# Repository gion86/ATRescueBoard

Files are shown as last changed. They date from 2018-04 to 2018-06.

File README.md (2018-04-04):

# ATRescueBoard
### Full credit for the original version to Jeff Keyzer [http://mightyohm.com](http://mightyohm.com)

Atmel "rescue" board for ATMega and ATTiny X4/X5: to recover fuses setting with High Voltage Programming. 

The PCB is a simplified Arduino shield, with sockets for ATMega and ATTiny; as 12V source the Vin Arduino 
pin has to be used, so the **Arduino must be powered externally with a 12V power supply!**

The micro code is uploaded to the ATmega328P on the Arduino, and comunicate with the user via the serial
interface. Three different mode can be selected:
* ATMEGA: mode for ATmega 128/168/328;
* TINY2313: not supported in this hardware version, look for original version at [https://mightyohm.com/blog/products/hv-rescue-shield-2-x/](https://mightyohm.com/blog/products/hv-rescue-shield-2-x/);
* HVSP: mode for ATtiny X4/X5;

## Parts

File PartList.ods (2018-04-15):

Part | Value | Device | Package | Library
ANA_IN |  | PINHD-1X6 | 1X06 | PIN HEADER | x
C1 | 100n | C-EU050-024X044 | C050-024X044 | CAPACITOR, European | x
DIG0_7 |  | PINHD-1X8 | 1X08 | PIN HEADER | x
DIG8_13 |  | PINHD-1X8 | 1X08 | PIN HEADER | x
LED1 | RED | LED5MM | LED5MM | MightyOhm Engineerin | x
LED2 | GREEN | LED5MM | LED5MM | MightyOhm Engineerin | x
MCU1 | ATMEGA | MEGA48/88/168-PU | DIL28-3 |  | x
MCU2 | ATTINY84ATTINY84-20PU | ATTINY84ATTINY84-20PU | DIL14 | Atmel 14-pin 2/4/8kB | x
MCU3 | TINY85-20-DIP | ATTINY45TINY85-20-DIP | DIP08 | Atmel 8-pin 2/4/8kB | x
POWER |  | PINHD-1X7 | 1X07 | PIN HEADER | x
Q1 | 2N3904 | 2N3904 | TO92- | NPN Transistor | x
R1 | 1k | R-US_0204/7 | 0204/7 | RESISTOR, American s | x
R2 | 5K6 | R-US_0207/10 | 0207/10 | RESISTOR, American s | x
R3 | 390 | R-US_0309/12 | 0309/12 | RESISTOR, American s | x
R4 | 560 | R-US_0309/12 | 0309/12 | RESISTOR, American s | x
R5 | 4K7 | R-US_0204/7 | 0204/7 | RESISTOR, American s | x
R6 | 560 | R-US_0309/12 | 0309/12 | RESISTOR, American s | x
SW1 |  | SWITCH_PUSHBUTTONEVQ-PE | TACT_PANA-EVQ | Buttons | x
TP1 | 12V_SW | TPPTH | TP_PTH | Test Point | x

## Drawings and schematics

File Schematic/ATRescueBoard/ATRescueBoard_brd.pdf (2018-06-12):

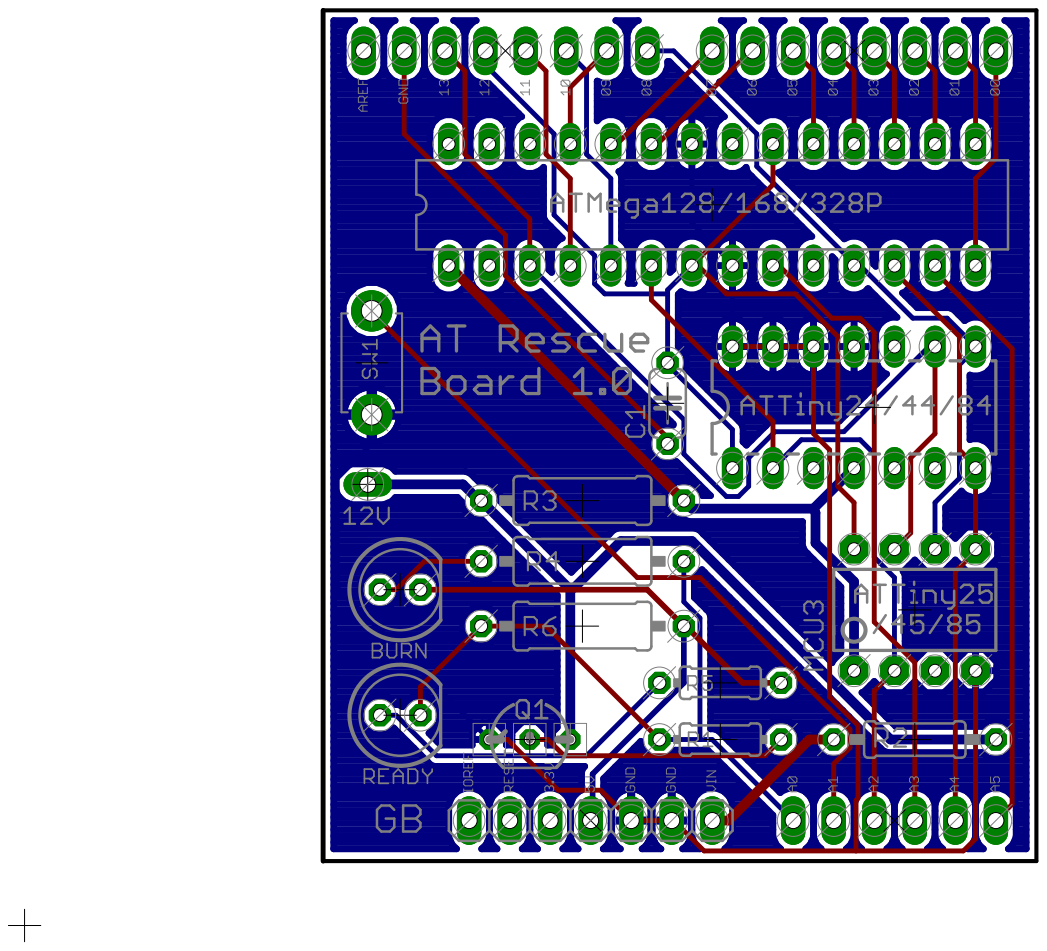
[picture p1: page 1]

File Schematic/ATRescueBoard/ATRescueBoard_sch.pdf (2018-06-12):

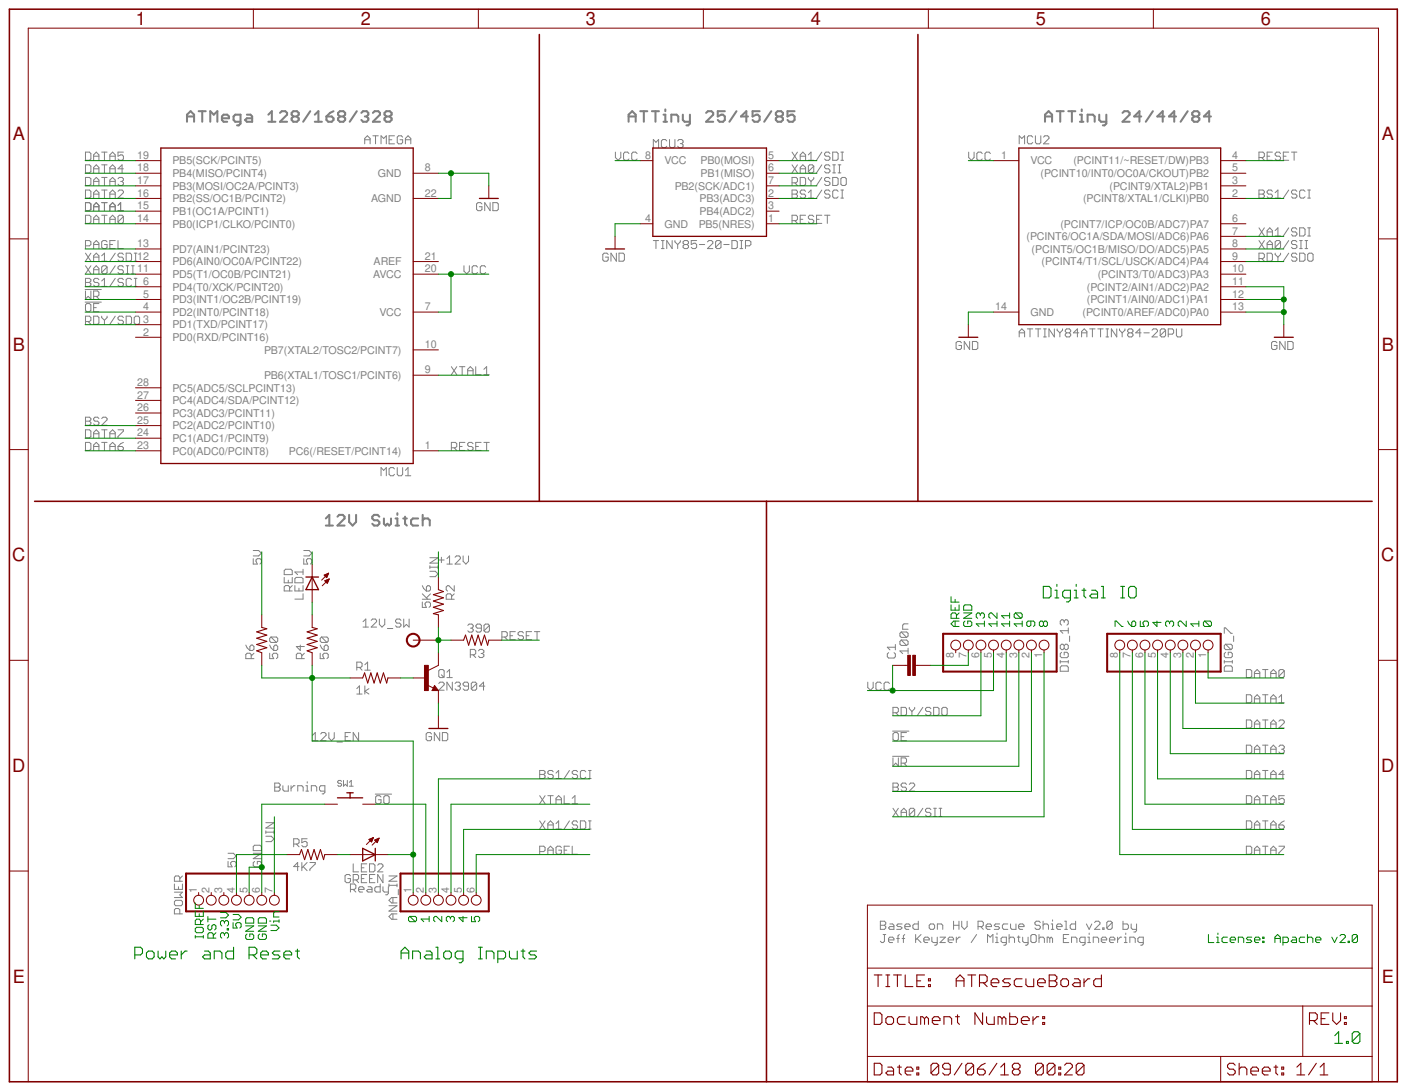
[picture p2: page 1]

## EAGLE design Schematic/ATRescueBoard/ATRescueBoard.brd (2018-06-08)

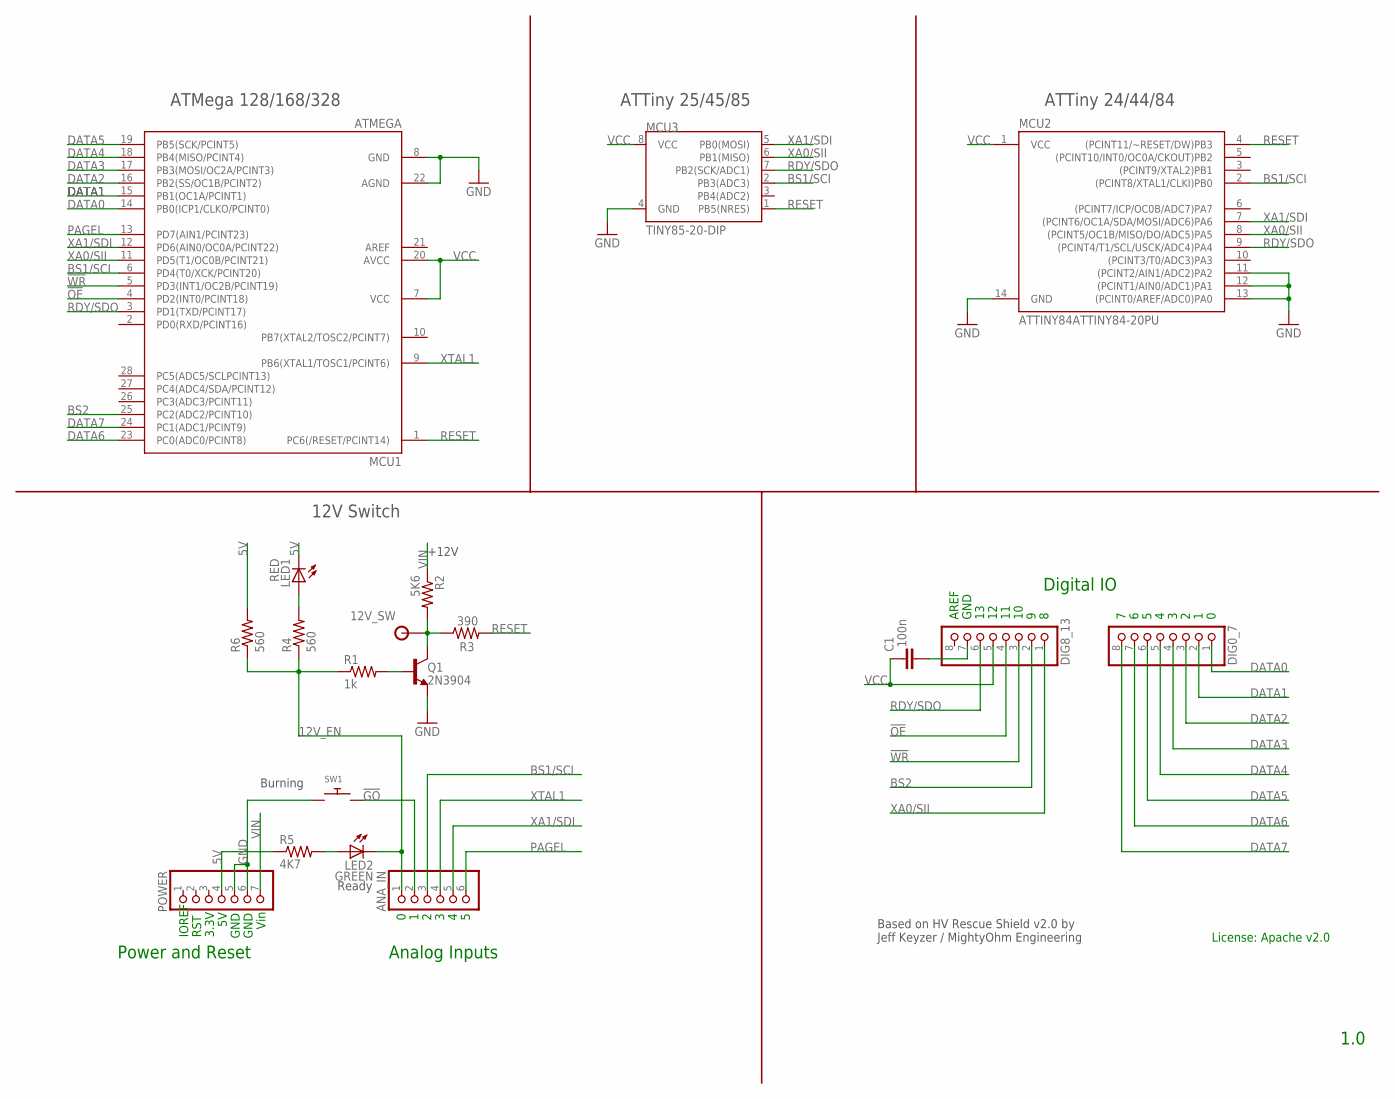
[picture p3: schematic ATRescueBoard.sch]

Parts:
ANA_IN: PINHD-1X6; 1X06
C1: 100n; C050-024X044
DIG0_7, DIG8_13: PINHD-1X8; 1X08
LED1: RED; LED5MM
LED2: GREEN; LED5MM
MCU1: ATMEGA; DIL28-3
MCU2: ATTINY84ATTINY84-20PU; DIL14
MCU3: TINY85-20-DIP; DIP08
POWER: PINHD-1X7; 1X07
Q1: 2N3904; TO92-
R1: 1k; 0204/7
R2: 5K6; 0207/10
R3: 390; 0309/12
R4, R6: 560; 0309/12
R5: 4K7; 0204/7
SW1: SWITCH_PUSHBUTTONEVQ-PE; TACT_PANA-EVQ
TP1: 12V_SW; TP_PTH

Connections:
5V: LED1.K (C), POWER.4, R5.1, R6.2
12V_EN: ANA_IN.1, LED2.K (C), R1.1, R4.1, R6.1
12V_SW: Q1.1 (C), R2.2, R3.1, TP1.P$1
!GO: ANA_IN.2, SW1.P$2
!OE: DIG8_13.4, MCU1.4 (PD2(INT0/PCINT18))
!WR: DIG8_13.3, MCU1.5 (PD3(INT1/OC2B/PCINT19))
BS1/SCI: ANA_IN.3, MCU1.6 (PD4(T0/XCK/PCINT20)), MCU2.2 ((PCINT8/XTAL1/CLKI)PB0), MCU3.2 (PB3(ADC3))
BS2: DIG8_13.2, MCU1.25 (PC2(ADC2/PCINT10))
DATA0: DIG0_7.1, MCU1.14 (PB0(ICP1/CLKO/PCINT0))
DATA1: DIG0_7.2, MCU1.15 (PB1(OC1A/PCINT1))
DATA2: DIG0_7.3, MCU1.16 (PB2(SS/OC1B/PCINT2))
DATA3: DIG0_7.4, MCU1.17 (PB3(MOSI/OC2A/PCINT3))
DATA4: DIG0_7.5, MCU1.18 (PB4(MISO/PCINT4))
DATA5: DIG0_7.6, MCU1.19 (PB5(SCK/PCINT5))
DATA6: DIG0_7.7, MCU1.23 (PC0(ADC0/PCINT8))
DATA7: DIG0_7.8, MCU1.24 (PC1(ADC1/PCINT9))
GND: MCU1.8 (GND), MCU1.22 (AGND), MCU2.11 ((PCINT2/AIN1/ADC2)PA2), MCU2.12 ((PCINT1/AIN0/ADC1)PA1), MCU2.13 ((PCINT0/AREF/ADC0)PA0), MCU2.14 (GND), MCU3.4 (GND), POWER.5, POWER.6, Q1.3 (E), SW1.P$1
unnamed: Q1.2 (B), R1.2
unnamed: LED1.A, R4.2
unnamed: LED2.A, R5.2
unnamed: C1.1, DIG8_13.7
PAGEL: ANA_IN.6, MCU1.13 (PD7(AIN1/PCINT23))
RDY/SDO: DIG8_13.6, MCU1.3 (PD1(TXD/PCINT17)), MCU2.9 ((PCINT4/T1/SCL/USCK/ADC4)PA4), MCU3.7 (PB2(SCK/ADC1))
RESET: MCU1.1 (PC6(/RESET/PCINT14)), MCU2.4 ((PCINT11/~RESET/DW)PB3), MCU3.1 (PB5(NRES)), R3.2
VCC: C1.2, DIG8_13.5, MCU1.7 (VCC), MCU1.20 (AVCC), MCU2.1 (VCC), MCU3.8 (VCC)
VIN: POWER.7, R2.1
XA0/SII: DIG8_13.1, MCU1.11 (PD5(T1/OC0B/PCINT21)), MCU2.8 ((PCINT5/OC1B/MISO/DO/ADC5)PA5), MCU3.6 (PB1(MISO))
XA1/SDI: ANA_IN.5, MCU1.12 (PD6(AIN0/OC0A/PCINT22)), MCU2.7 ((PCINT6/OC1A/SDA/MOSI/ADC6)PA6), MCU3.5 (PB0(MOSI))
XTAL1: ANA_IN.4, MCU1.9 (PB6(XTAL1/TOSC1/PCINT6))

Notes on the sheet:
Analog Inputs
Power and Reset
Digital IO
Vin
GND
RST
3.3V
Based on HV Rescue Shield v2.0 by Jeff Keyzer / MightyOhm Engineering
AREF
Ready
Burning
License: Apache v2.0
IOREF
+12V
ATTiny 25/45/85
ATMega 128/168/328
ATTiny 24/44/84
12V Switch

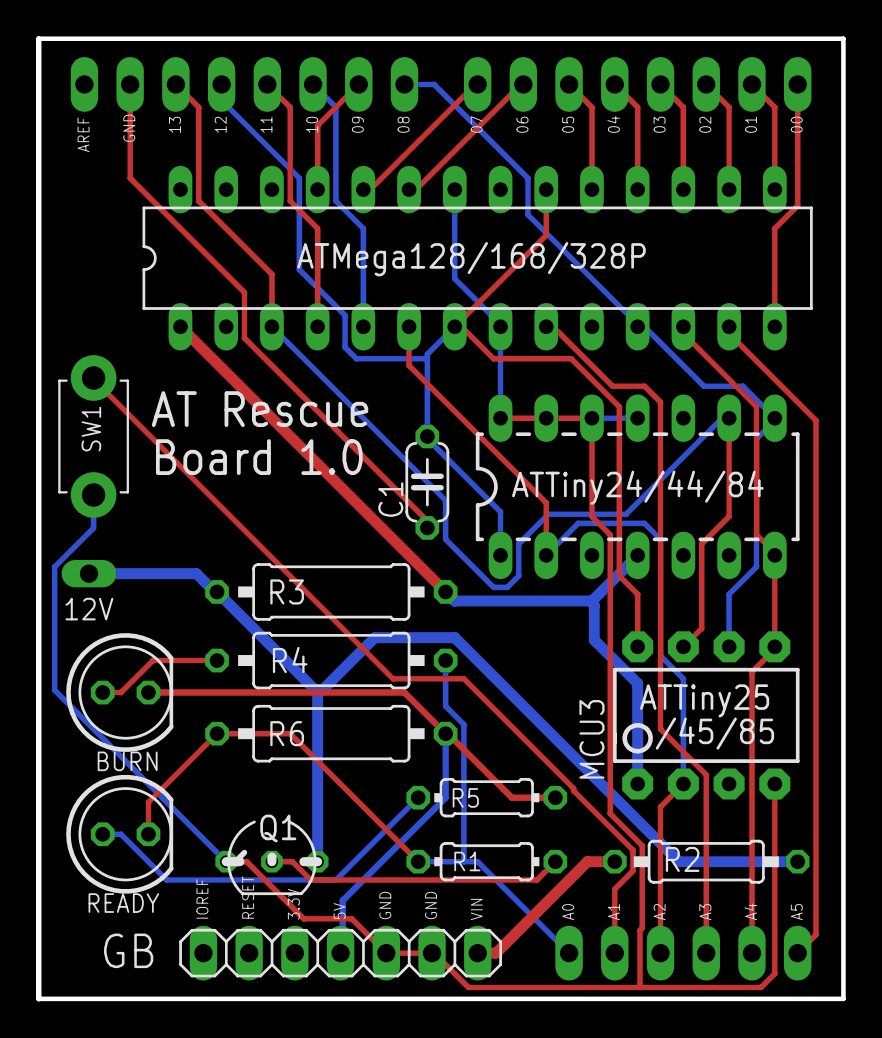
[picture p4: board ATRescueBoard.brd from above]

Board: 2 copper layers, 44.7 x 53.3 mm, 20 parts (0 on the bottom side), 29 nets.

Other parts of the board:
DRILEGEND: DRILEGEND

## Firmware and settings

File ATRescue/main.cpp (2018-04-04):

/*
  Title:        HVRescue_Shield
  Description:  Arduino sketch for use with the HV Rescue Shield
  Author:       Jeff Keyzer
  Company:      MightyOhm Engineering
  Website:      http://mightyohm.com
  Contact:      http://mightyohm.com/blog/contact/

  This sketch assumes that the Arduino is equipped with an AVR HV Rescue Shield.
  Schematics and other details are available at http://mightyohm.com/hvrescue2

  The sketch uses High Voltage Programming Mode to set fuses on many Atmel AVR family 8-bit microcontrollers.
  Version 2.0 adds support for High Voltage Serial Programming (HVSP) mode and 8-pin ATtiny devices, but remains
  backwards compatible with the 1.x series hardware.

  The HVPP routines are based on those described in the ATmega48/88/168 datasheet rev.
  2545M-AVR-09/07, pg. 290-297 and the ATtiny2313 datasheet rev. 2543I-AVR-04/06 pg. 165-176.

  The HVSP routines are based on the ATtiny25/45/85 and 13A datasheets (ATtiny25/45/85 2586M–AVR–07/10 pg. 159-165,
  ATtiny13A 8126E-AVR-7/10 pg. 109-116).

  These routines are compatible with many other members of the AVR family that are not listed here.
  For a complete list of tested microcontrollers, see http://mightyohm.com/wiki/products:hvrescue:compatibility

  Changelog:
  31/03/18 2.13 Gionata Boccalini
   - moved function on top of setup and loop (to compile without function prototypes)
   - changed the logic on RST pin: now is inverting
   - fixed some compiler warnings

  3/15/11 2.12
    - new digital pin 0-7 (command&data) read/write routines for the Arduino Mega, since these lines are implemented
      differently on the Mega than on the original Arduino.

  3/8/11 2.11
    - analog inputs (used here as digital outputs) are now called by their new Arduino A0-A5 names.

  2/2/11 2.1
    - adjusted RESET and VCC edge timing to work with new board design and avoid signal contention on SDO
    - fixed bug that prevented program from compiling in non-interactive mode
    - modified non-interactive mode so that read/verify serial comms still occur, but fuse values aren't prompted

  12/17/10 2.01
    - added missing braces to if(mode == HVSP) that sets SDO pinmode to INPUT
    - removed misleading comment about removing AVR when entering fuse values
    - default mode changed back to ATMEGA

  12/13/10 v2.0
    - Added support for 8-pin parts that use HV Serial Programming (HVSP)
    - New mode selection at startup determines which type of part is to be programmed
    - Got rid of endSerial function, since Arduino now includes Serial.end (finally!)
    - Added a wait for serial transmit to complete before burning fuses.  Without this HFUSE burn would fail occasionally.
    - Numerous other minor tweaks, removal of unnecessary delays, better commenting

  9/24/10 v1.2a
    - ATtiny2313 mode was being set by default.  Changed default mode back to ATmega (see #define ATtiny).

  8/16/10 v1.2
    - Existing fuse settings are now shown before asking the user for new values
    - Added OE strobe after entering programming mode to get ATtiny2313 to read first fuse correctly.
    - Cleaned up code a bit
    - Some minor tweaks to data direction register settings during setup, etc.

  11/02/09 v1.1
    - Removed endSerial call after reading back fuse bytes, was spewing garbage into
      serial monitor
    - Still occsionally get garbage when opening serial monitor, not sure what is causing this.

  03/01/09 v1.0
    - ATtiny2313 support, enable with ATtiny option
    - 12V Step up converter enable is non-inverting, unlike previous level shifter circuit
    - added interactive mode, asks for fuse values to burn, option to turn off
    - added EFUSE support and option to enable
    - button now has very simple debounce routine

  09/24/08
    - original release of sketch "HVFuse" to support first implementation on perfboard
    - Details: http://mightyohm.com/blog/2008/09/arduino-based-avr-high-voltage-programmer/

  Copyright 2008, 2009, 2010 Jeff Keyzer

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
  You should have received a copy of the GNU General Public License
  along with this program.  If not, see <http://www.gnu.org/licenses/>.
*/

#include <Arduino.h>

// User defined settings
#define  MEGA         0       // Set this to 1 if you are using an Arduino Mega (default = 0)
#define  DEFAULTMODE  ATMEGA  // If running in non-interactive mode, you need to set this to ATMEGA, TINY2313, or HVSP.
#define  ASKMODE      1       // Set this to 1 to enable mode question at startup
#define  INTERACTIVE  1       // Set this to 0 to disable interactive (serial) mode
#define  BURN_EFUSE   0       // Set this to 1 to enable burning extended fuse byte
#define  BAUD         9600    // Serial port rate at which to talk to PC

// If interactive mode is off, these fuse settings are used instead of user prompted values
#define  LFUSE        0x62    // default for ATmega168 = 0x62
#define  HFUSE        0xDF    // default for ATmega168 = 0xDF
#define  EFUSE        0xF9    // default for ATmega168 = 0xF9

/*
  Data line assignments
  Fuse and command data for HVPP mode are sent using Arduino digital lines 0-7

  Arduino Uno and other original-style form factor boards:
    Digital Line 0-7 outputs = PORTD
    Inputs = PIND
    Data direction register = DDRD

  Arduino Mega - much more complicated because digital lines 0-7 don't map directly to an AVR hardware port:
    Digital Line  AVR Signal Name
    0  PE0  (PORTE)
    1  PE1  (PORTE)
    2  PE4  (PORTE)
    3  PE5  (PORTE)
    4  PG5  (PORTG)
    5  PE3  (PORTE)
    6  PH3  (PORTH)
    7  PH4  (PORTH)
*/

// Pin Assignments (you shouldn't need to change these)
#define  VCC     12
#define  RDY     13     // RDY/!BSY signal from target
#define  OE      11
#define  WR      10
#define  BS1     A2
#define  XA0     8
#define  XA1     A4
#define  RST     A0     // 12V Step up converter enable (12V_EN)
#define  XTAL1   A3
#define  BUTTON  A1     // Run button

// Pin assignments for HVSP mode
#define  SCI    BS1
#define  SDO    RDY
#define  SII    XA0
#define  SDI    XA1

// Serial instructions for HVSP mode
// Based on the ATtiny85 datasheet Table 20-16 pg. 163-165.
// These instructions don't contain the necessary zero padding, which is added later.

// LFUSE
#define HVSP_READ_LFUSE_DATA     B00000100  // For the commands we are interested in
#define HVSP_READ_LFUSE_INSTR1   B01001100  // only the 1st instruction contains a fixed data packet.
#define HVSP_READ_LFUSE_INSTR2   B01101000  // Instructions 2-3 have data = all zeros.
#define HVSP_READ_LFUSE_INSTR3   B01101100

#define HVSP_WRITE_LFUSE_DATA    B01000000  // For the write instructions, the data contents
#define HVSP_WRITE_LFUSE_INSTR1  B01001100  // for instruction 2 are the desired fuse bits.
#define HVSP_WRITE_LFUSE_INSTR2  B00101100  // Instructions 3-4 have data = all zeros.
#define HVSP_WRITE_LFUSE_INSTR3  B01100100
#define HVSP_WRITE_LFUSE_INSTR4  B01101100

// HFUSE
#define HVSP_READ_HFUSE_DATA     B00000100
#define HVSP_READ_HFUSE_INSTR1   B01001100
#define HVSP_READ_HFUSE_INSTR2   B01111010
#define HVSP_READ_HFUSE_INSTR3   B01111110

#define HVSP_WRITE_HFUSE_DATA    B01000000
#define HVSP_WRITE_HFUSE_INSTR1  B01001100
#define HVSP_WRITE_HFUSE_INSTR2  B00101100
#define HVSP_WRITE_HFUSE_INSTR3  B01110100
#define HVSP_WRITE_HFUSE_INSTR4  B01111100

// EFUSE
// Note: not all ATtiny's have an EFUSE
#define HVSP_READ_EFUSE_DATA     B00000100
#define HVSP_READ_EFUSE_INSTR1   B01001100
#define HVSP_READ_EFUSE_INSTR2   B01101010
#define HVSP_READ_EFUSE_INSTR3   B01101110

#define HVSP_WRITE_EFUSE_DATA    B01000000
#define HVSP_WRITE_EFUSE_INSTR1  B01001100
#define HVSP_WRITE_EFUSE_INSTR2  B00101100
#define HVSP_WRITE_EFUSE_INSTR3  B01100110
#define HVSP_WRITE_EFUSE_INSTR4  B01101110

// Enable debug mode by uncommenting this line
//#define DEBUG

// Internal definitions
enum modelist { ATMEGA, TINY2313, HVSP };
enum fusesel { LFUSE_SEL, HFUSE_SEL, EFUSE_SEL };

// Global variables
byte mode = DEFAULTMODE;  // programming mode

// These pin assignments change depending on which chip is being programmed,
// so they can't be set using #define
// There is probably a more elegant way to do this.  Suggestions?
byte PAGEL = A5;  // ATtiny2313: PAGEL = BS1
byte BS2 = 9;     // ATtiny2313: BS2 = XA1


void sclk(void) {  // send serial clock pulse, used by HVSP commands

  // These delays are much  longer than the minimum requirements,
  // but we don't really care about speed.
  delay(1);
  digitalWrite(SCI, HIGH);
  delay(1);
  digitalWrite(SCI, LOW);
}

void strobe_xtal(void) {  // strobe xtal (usually to latch data on the bus)

  delay(1);
  digitalWrite(XTAL1, HIGH);  // pulse XTAL to send command to target
  delay(1);
  digitalWrite(XTAL1, LOW);
}

int hex2dec(byte c) { // converts one HEX character into a number
  if (c >= '0' && c <= '9') {
    return c - '0';
  }
  else if (c >= 'A' && c <= 'F') {
    return c - 'A' + 10;
  }
  return c;
}

void send_cmd(byte command)  // Send command to target AVR
{
  // Set controls for command mode
  digitalWrite(XA1, HIGH);
  digitalWrite(XA0, LOW);
  digitalWrite(BS1, LOW);

  if (mode != TINY2313)
    digitalWrite(BS2, LOW);  // Command load seems not to work if BS2 is high


  #if (MEGA == 0)
    PORTD = command;
    DDRD = 0xFF;  // Set all DATA lines to outputs
  #else
    mega_data_write(command);
  #endif

  strobe_xtal();  // latch DATA

  #if (MEGA == 0)
    PORTD = 0x00;
    DDRD = 0x00;  // reset DATA to input to avoid bus contentions
  #else
    mega_data_input();
  #endif
}

void fuse_burn(byte fuse, int select)  // write high or low fuse to AVR
{

  send_cmd(B01000000);  // Send command to enable fuse programming mode

  // Enable data loading
  digitalWrite(XA1, LOW);
  digitalWrite(XA0, HIGH);
  // Specify low byte
  digitalWrite(BS1, LOW);
  if (mode != TINY2313)
    digitalWrite(BS2, LOW);
  delay(1);

  // Load fuse value into target
  #if (MEGA == 0)
    PORTD = fuse;

    DDRD = 0xFF;  // Set all DATA lines to outputs
  #else
    mega_data_write(fuse);
  #endif

  strobe_xtal();  // latch DATA

  #if (MEGA == 0)
    PORTD = 0x00;
    DDRD = 0x00;  // reset DATA to input to avoid bus contentions
  #else
    mega_data_input();
  #endif

  // Decide which fuse location to burn
  switch (select) {
  case HFUSE_SEL:
    digitalWrite(BS1, HIGH); // program HFUSE
    digitalWrite(BS2, LOW);
    break;
  case LFUSE_SEL:
    digitalWrite(BS1, LOW);  // program LFUSE
    digitalWrite(BS2, LOW);
    break;
  case EFUSE_SEL:
    digitalWrite(BS1, LOW);  // program EFUSE
    digitalWrite(BS2, HIGH);
    break;
  }
  delay(1);
   // Burn the fuse
  digitalWrite(WR, LOW);
  delay(1);
  digitalWrite(WR, HIGH);
  //delay(100);

  while(digitalRead(RDY) == LOW);  // when RDY goes high, burn is done

  // Reset control lines to original state
  digitalWrite(BS1, LOW);
  digitalWrite(BS2, LOW);
}

byte fuse_read(int select) {
  byte fuse;

  send_cmd(B00000100);  // Send command to read fuse bits

  // Configure DATA as input so we can read back fuse values from target
  #if (MEGA == 0)
    PORTD = 0x00;
    DDRD = 0x00;  // reset DATA to input to avoid bus contentions
  #else
    mega_data_input();
  #endif

  // Set control lines
  switch (select) {
    case LFUSE_SEL:
      // Read LFUSE
      digitalWrite(BS2, LOW);
      digitalWrite(BS1, LOW);
      break;
    case HFUSE_SEL:
      // Read HFUSE
      digitalWrite(BS2, HIGH);
      digitalWrite(BS1, HIGH);
      break;
    case EFUSE_SEL:
      // Read EFUSE
      digitalWrite(BS2, HIGH);
      digitalWrite(BS1, LOW);
      break;
  }

  //  Read fuse
  digitalWrite(OE, LOW);
  delay(1);

  #if (MEGA == 0)
    fuse = PIND;
  #else
    fuse = mega_data_read();
  #endif

  digitalWrite(OE, HIGH);  // Done reading, disable output enable line
  return fuse;
}

byte fuse_ask(void) {  // get desired fuse value from the user (via the serial port)
  byte incomingByte = 0;
  byte fuse;
  char serbuffer[2];

  while (incomingByte != 'x') {  // crude way to wait for a hex string to come in
    while (Serial.available() == 0);   // wait for a character to come in
    incomingByte = Serial.read();
  }

  // Hopefully the next two characters form a hex byte.  If not, we're hosed.
  while (Serial.available() == 0);   // wait for character
  serbuffer[0] = Serial.read();      // get high byte of fuse value
  while (Serial.available() == 0);   // wait for character
  serbuffer[1] = Serial.read();      // get low byte

  fuse = hex2dec(serbuffer[1]) + hex2dec(serbuffer[0]) * 16;

  Serial.println(fuse, HEX);  // echo fuse value back to the user

  return fuse;

}
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
void loop() {  // run over and over again

  byte hfuse, lfuse;            // desired fuse values from user
  byte read_hfuse, read_lfuse;  // fuses read from target for verify

#if (BURN_EFUSE == 1)
  byte efuse;                   // desired fuse values from user
  byte read_efuse;              // fuses read from target for verify
#endif

  Serial.println("Insert target AVR and press button.");
  Serial.end();

  // Set lower 2 bits of DATA low.  This helps avoid serial garbage showing up when you insert a part.
  #if (MEGA == 0)
    DDRD = 0x03;
    PORTD = 0x00;
  #else  // Lower 2 bits are part of PORTE on the Mega
    PORTE &= ~(_BV(PE0) | _BV(PE1));
    DDRE |= (_BV(PE0) | _BV(PE1));
  #endif

  // wait for button press, debounce
  while(1) {
    while (digitalRead(BUTTON) == HIGH);  // wait here until button is pressed
    delay(100);                            // simple debounce routine
    if (digitalRead(BUTTON) == LOW)       // if the button is still pressed, continue
      break;  // valid press was detected, continue on with rest of program
  }
  // Initialize pins to enter programming mode
  #if (MEGA == 0)  // Set up data lines on original Arduino
    PORTD = 0x00;  // clear digital pins 0-7
    DDRD = 0x00;  // set digital pins 0-7 as inputs for now
  #else
    mega_data_input();
  #endif
  digitalWrite(PAGEL, LOW);
  digitalWrite(XA1, LOW);
  digitalWrite(XA0, LOW);
  digitalWrite(BS1, LOW);
  digitalWrite(BS2, LOW);
  digitalWrite(WR, LOW);  // ATtiny2313 needs this to be low to enter programming mode, ATmega doesn't care
  digitalWrite(OE, LOW);

  if(mode == HVSP) {
    digitalWrite(SDI, LOW);  // set necessary pin values to enter programming mode
    digitalWrite(SII, LOW);
    pinMode(SDO, OUTPUT);    // SDO is same as RDY pin
    digitalWrite(SDO, LOW);  // needs to be low to enter programming mode
  }

  // Enter programming mode
  digitalWrite(VCC, HIGH);  // Apply VCC to start programming process
  delayMicroseconds(80);
  digitalWrite(RST, LOW);   // Apply 12V to !RESET

  if(mode == HVSP) {
    // reset SDO after short delay, longer leads to logic contention because target sets SDO high after entering programming mode
    delayMicroseconds(1);   // datasheet says 10us, 1us is needed to avoid drive contention on SDO
    pinMode(SDO, INPUT);    // set to input to avoid logic contention
  }

  delayMicroseconds(10);  // Give lots of time for part to enter programming mode
  digitalWrite(OE, HIGH);
  digitalWrite(WR, HIGH);   // Now that we're in programming mode we can disable !WR
  delay(1);

  /****
   **** Now we're in programming mode until RST is set HIGH again
   ****/

  if (mode == HVSP) {
    HVSP_read(HVSP_READ_LFUSE_DATA, HVSP_READ_LFUSE_INSTR1);
    HVSP_read(0x00, HVSP_READ_LFUSE_INSTR2);
    read_lfuse = HVSP_read(0x00, HVSP_READ_LFUSE_INSTR3);

    HVSP_read(HVSP_READ_HFUSE_DATA, HVSP_READ_HFUSE_INSTR1);
    HVSP_read(0x00, HVSP_READ_HFUSE_INSTR2);
    read_hfuse = HVSP_read(0x00, HVSP_READ_HFUSE_INSTR3);

    #if (BURN_EFUSE == 1)
      HVSP_read(HVSP_READ_EFUSE_DATA, HVSP_READ_EFUSE_INSTR1);
      HVSP_read(0x00, HVSP_READ_EFUSE_INSTR2);
      read_efuse = HVSP_read(0x00, HVSP_READ_EFUSE_INSTR3);
    #endif

  } else {

    // Get current fuse settings stored on target device
    read_lfuse = fuse_read(LFUSE_SEL);
    read_hfuse = fuse_read(HFUSE_SEL);
    #if (BURN_EFUSE == 1)
      read_efuse = fuse_read(EFUSE_SEL);
    #endif
  }

  // Open serial port again to print fuse values
  Serial.begin(BAUD);
  Serial.print("\n");
  Serial.println("Existing fuse values:");
  Serial.print("LFUSE: ");
  Serial.println(read_lfuse, HEX);
  Serial.print("HFUSE: ");
  Serial.println(read_hfuse, HEX);
  #if (BURN_EFUSE == 1)
    Serial.print("EFUSE: ");
    Serial.println(read_efuse, HEX);
  #endif
  Serial.print("\n");

  #if (INTERACTIVE == 1)
    // Ask the user what fuses should be burned to the target
    // For a guide to AVR fuse values, go to http://www.engbedded.com/cgi-bin/fc.cgi
    Serial.print("Enter desired LFUSE hex value (ie. 0x62): ");
    lfuse = fuse_ask();
    Serial.print("Enter desired HFUSE hex value (ie. 0xDF): ");
    hfuse = fuse_ask();

    #if (BURN_EFUSE == 1)
      Serial.print("Enter desired EFUSE hex value (ie. 0xF9): ");
      efuse = fuse_ask();
    #endif

  #else  // not using interactive mode, just set fuses to values defined in header
    hfuse = HFUSE;
    lfuse = LFUSE;
    efuse = EFUSE;
  #endif

  // This business with TXC0 is required because Arduino doesn't give us a means to tell if a serial
  // transmission is complete before we move on and do other things.  If we don't wait for TXC0 to be reset,
  // I found that sometimes the 1st fuse burn would fail.  It turns out that DATA1 (which doubles as Arduino serial
  // TX) was still toggling by the time the 1st XTAL strobe latches the fuse program command.  Bad news.

  UCSR0A |= _BV(TXC0);  // Reset serial transmit complete flag (need to do this manually because TX interrupts aren't used by Arduino)
  Serial.println("Burning fuses...");
  while(!(UCSR0A & _BV(TXC0)));  // Wait for serial transmission to complete before burning fuses!

  Serial.end();    // We're done with serial comms (for now) so disable UART

  // Now burn desired fuses
  // How we do this depends on which mode we're in
  if (mode == HVSP) {
    HVSP_write(HVSP_WRITE_LFUSE_DATA, HVSP_WRITE_LFUSE_INSTR1);
    HVSP_write(lfuse, HVSP_WRITE_LFUSE_INSTR2);
    HVSP_write(0x00, HVSP_WRITE_LFUSE_INSTR3);
    HVSP_write(0x00, HVSP_WRITE_LFUSE_INSTR4);
    while(digitalRead(SDO) == LOW);  // wait until burn is done

    HVSP_write(HVSP_WRITE_HFUSE_DATA, HVSP_WRITE_HFUSE_INSTR1);
    HVSP_write(hfuse, HVSP_WRITE_HFUSE_INSTR2);
    HVSP_write(0x00, HVSP_WRITE_HFUSE_INSTR3);
    HVSP_write(0x00, HVSP_WRITE_HFUSE_INSTR4);
    while(digitalRead(SDO) == LOW);

    #if (BURN_EFUSE == 1)
      HVSP_write(HVSP_WRITE_EFUSE_DATA, HVSP_WRITE_EFUSE_INSTR1);
      HVSP_write(efuse, HVSP_WRITE_EFUSE_INSTR2);
      HVSP_write(0x00, HVSP_WRITE_EFUSE_INSTR3);
      HVSP_write(0x00, HVSP_WRITE_EFUSE_INSTR4);
      while(digitalRead(SDO) == LOW);
    #endif

    // Read back fuse contents to verify burn worked
    HVSP_read(HVSP_READ_LFUSE_DATA, HVSP_READ_LFUSE_INSTR1);
    HVSP_read(0x00, HVSP_READ_LFUSE_INSTR2);
    read_lfuse = HVSP_read(0x00, HVSP_READ_LFUSE_INSTR3);
    HVSP_read(HVSP_READ_HFUSE_DATA, HVSP_READ_HFUSE_INSTR1);
    HVSP_read(0x00, HVSP_READ_HFUSE_INSTR2);
    read_hfuse = HVSP_read(0x00, HVSP_READ_HFUSE_INSTR3);

    #if (BURN_EFUSE == 1)
      HVSP_read(HVSP_READ_EFUSE_DATA, HVSP_READ_EFUSE_INSTR1);
      HVSP_read(0x00, HVSP_READ_EFUSE_INSTR2);
      read_efuse = HVSP_read(0x00, HVSP_READ_EFUSE_INSTR3);
    #endif

    } else {
    //delay(10);

    // First, program HFUSE
    fuse_burn(hfuse, HFUSE_SEL);

    // Now, program LFUSE
    fuse_burn(lfuse, LFUSE_SEL);

    #if (BURN_EFUSE == 1)
      // Lastly, program EFUSE
      fuse_burn(efuse, EFUSE_SEL);
    #endif

    // Read back fuse contents to verify burn worked
    read_lfuse = fuse_read(LFUSE_SEL);
    read_hfuse = fuse_read(HFUSE_SEL);

    #if (BURN_EFUSE == 1)
      read_efuse = fuse_read(EFUSE_SEL);
    #endif

    // Done verifying
    digitalWrite(OE, HIGH);
  }

  Serial.begin(BAUD);  // open serial port
  Serial.print("\n");  // flush out any garbage data on the link left over from programming
  Serial.print("Read LFUSE: ");
  Serial.println(read_lfuse, HEX);
  Serial.print("Read HFUSE: ");
  Serial.println(read_hfuse, HEX);
  #if (BURN_EFUSE == 1)
    Serial.print("Read EFUSE: ");
    Serial.println(read_efuse, HEX);
  #endif
  Serial.println("Burn complete.");
  Serial.print("\n");
  Serial.println("It is now safe to remove the target AVR.");
  Serial.print("\n");

  // All done, disable outputs
  #if (MEGA == 0)  // Set up data lines on original Arduino
    PORTD = 0x00;  // clear digital pins 0-7
    DDRD = 0x00;  // set digital pins 0-7 as inputs for now
  #else
    mega_data_input();
  #endif
  digitalWrite(RST, HIGH);  // exit programming mode
  delay(1);
  digitalWrite(OE, LOW);
  digitalWrite(WR, LOW);
  digitalWrite(PAGEL, LOW);
  digitalWrite(XA1, LOW);
  digitalWrite(XA0, LOW);
  digitalWrite(BS1, LOW);
  digitalWrite(BS2, LOW);
  digitalWrite(VCC, LOW);
}

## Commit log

2018-04-04 Added first version of schematic and board. Arduino Uno code tested on breadboard
    [ATRescueBoard.brd, ATRescueBoard.sch, PartList.ods]
2018-04-15 Completed first version of schematic and board
    [ATRescueBoard.brd, ATRescueBoard.sch, PartList.ods]
2018-04-22 Added ground plane on brd and printed brd and sch pdf
    [ATRescueBoard.brd]
2018-05-17 Added fist version of gerber file for SeeedStudio
    [ATRescueBoard.GBL, ATRescueBoard.GBO, ATRescueBoard.GBP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]
2018-06-05 Made gerber file for board v1.0, ready for SeeedStudio
    [ATRescueBoard.sch]
2018-06-08 Reviewed tNames layer for labels in board file
    [ATRescueBoard.brd]
2018-06-12 Rerun cam on brd file to upload to SeeedStudio, deleted PNG folder
    [ATRescueBoard.GTO]

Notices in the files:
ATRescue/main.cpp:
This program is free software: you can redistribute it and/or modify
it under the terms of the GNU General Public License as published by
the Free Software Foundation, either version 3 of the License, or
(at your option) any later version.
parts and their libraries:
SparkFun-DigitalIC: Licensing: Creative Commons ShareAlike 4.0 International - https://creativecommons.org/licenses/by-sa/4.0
